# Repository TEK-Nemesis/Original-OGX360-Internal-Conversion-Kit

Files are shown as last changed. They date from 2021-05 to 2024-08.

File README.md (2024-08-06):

# Original OGX360 Internal Conversion Kit

This project allows an existing ogx360 to be nicely installed inside an original Xbox.

Note:  The ogx360 is a small circuit board which allows you to use a range of modern USB controllers on the Original Xbox Console.  It was designed by Ryzee119 (Ryan Wendland) and without him, I could not have made this product for the community.  https://github.com/Ryzee119/ogx360

Please consider donating to Ryan Wendland here:
<br>

## General:
* This project is a culmination of work that will aid with the installation of the original ogx360 (37mm x 97mm / 1.44 inches x 3.82 inches) inside an original Xbox.  
* Individual components of this project are organized into their own folder.
* If you don't already own an ogx360 then it is *not* recommended to use this kit.  If you are starting fresh then the better option is to use the newer internal OGX360i as it was made specifically to be installed inside an original Xbox.  (The TEK Nemesis OGX360i is very small in comparison to the original OGX360).

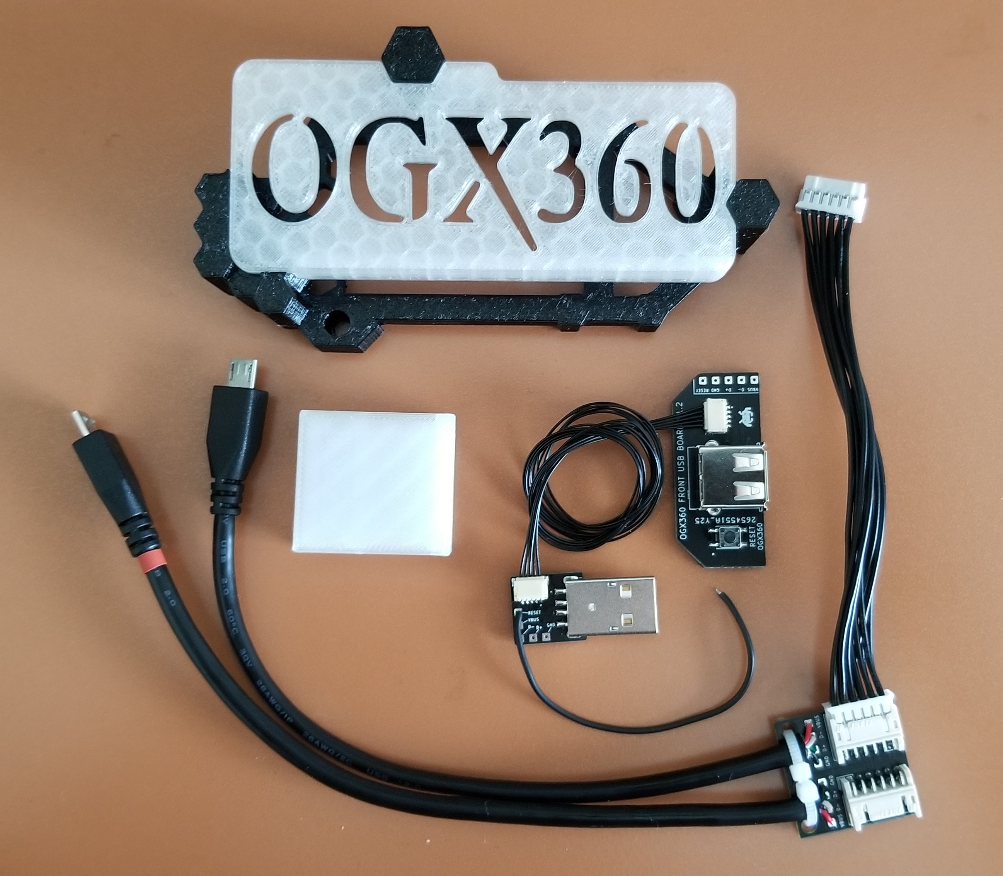
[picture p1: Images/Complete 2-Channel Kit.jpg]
 
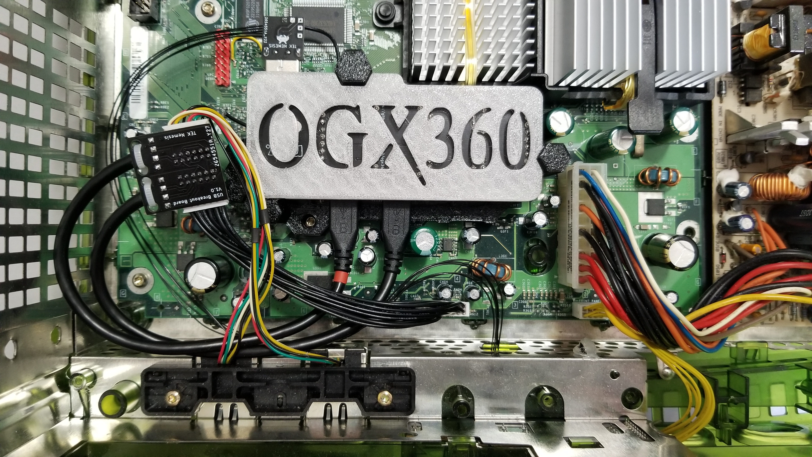
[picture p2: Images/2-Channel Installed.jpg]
 
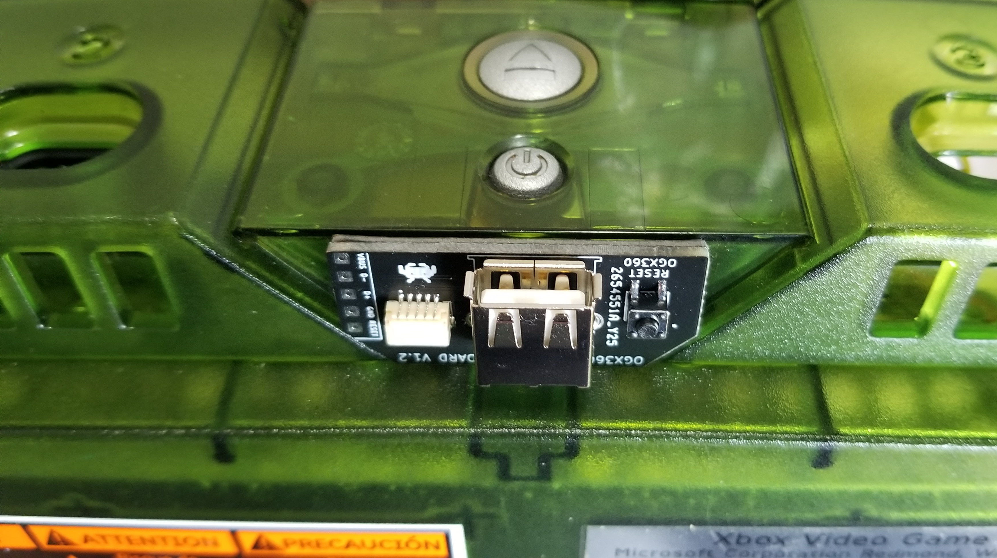
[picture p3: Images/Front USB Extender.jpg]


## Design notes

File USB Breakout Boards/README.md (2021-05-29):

# USB Breakout Boards

## Overview

* USB Breakout boards split USB functionality between the Xbox motherboard and the ogx360.  (The Xbox controller ports are actually proprietary USB ports.)

* I've included a little PCB that allows you two extend the 12-pin cable coming off the controller port.  Sometimes it is useful to use one with certain Xbox Revisions that don't have long Controller Port cables (e.g. 1.6).

* RYZEE119 designed the first USB Breakout Board to accept Micro USB to Micro USB Cables and 12-pin JST cables 2.00mm pitch.  The PCB is very small, measuring around 1 sq. in. in size.

* TEK Nemesis designed the second USB Breakout Board for direct wiring of the Micro USB cables to the PCB (and the same 12-pin JST cables 2.00mm pitch).

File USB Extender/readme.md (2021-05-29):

# USB Extender

## Overview

The USB Extender simply extends the USB port on the ogx360, bringing a USB port to the front of the Xbox.  

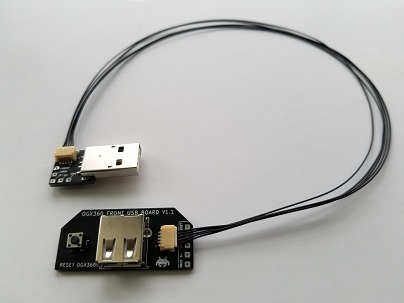
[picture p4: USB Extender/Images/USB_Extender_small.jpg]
 

## Usage

- The installation of a tactile switch on the Front USB PCB is optional but it may prove useful (perhaps when switching from wired to wireless controllers).  If used, here is what must be done:

   * If you **are** using a JST cable to connect the two USB Extender PCBs then you simply need to solder one end of a wire (e.g. 28 AWG multi-stranded) to the **reset** solder pad on the USB Plug PCB (that plugs directly into the ogx360).  The other end of the wire gets soldered to one of two inside pads of the tactile switch (that is soldered onto the ogx360).  Refer to the picture below.

   * If you **are not** using a JST cable to connect the two USB Extender PCBs then you will run one single wire (e.g. 28 AWG multi-stranded) from the **reset** solder pad on the Front USB PCB to one of two inside pads of the tactile switch (that is soldered onto the ogx360).  Refer to the picture below.
 
Note:  If everything is connected and the ogx360 doesn't reset then solder the reset wire to a different pad on the ogx360's tactile switch.  

- A 5-pin 1.00mm pitch JST cable is used to connect the two parts (although you may also wire directly to the solder pads.)

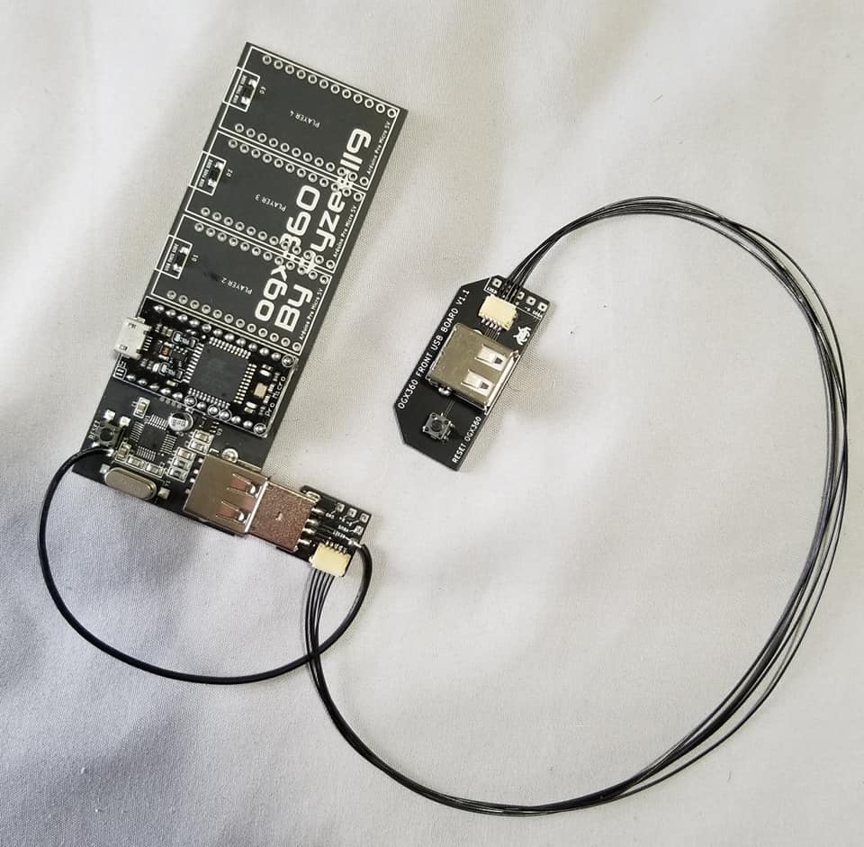
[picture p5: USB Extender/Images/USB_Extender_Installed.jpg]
 

## Gerber files

<b>USB 2.0 Plug for ogx360.zip</b> - plugs directly into the ogx360 USB Port.  A 5-pin cable runs out to the Front USB piece.  (Optionally, single wires may be used.)

<b>OGX360 Front USB PCB_Gerber Files (Type A).zip</b> - this PCB gets mounted outside the case, centred under the power/eject buttons.  Use double-sided tape to secure it.  5-pin connector points to <b>side</b>.   

<b>OGX360 Front USB PCB_Gerber Files (Type B).zip</b> - this PCB gets mounted outside the case, centred under the power/eject buttons.  Use double-sided tape to secure it.  5-pin connector points to <b>rear</b>.

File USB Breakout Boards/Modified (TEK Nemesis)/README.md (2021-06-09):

# USB Breakout Board (by TEK Nemesis)

## Overview

* This PCB was designed by TEK Nemesis. It uses Micro USB cables (cut open at one end) and 12-pin JST 2.00mm cables.  Zip ties / cable ties (optional) hold the wires nicely in place.
* This design allows for better cable management and routing.
* The Micro USB cable is soldered to the PCB like this (though it is possible to have alternate wire colours):
  - red wire to VBUS
  - black wire to GND
  - green wire to D+
  - white wire to D-
* Note that there are markings on the PCB to indicate the Controller Port:  P1/P3, P2/P4.  Plug the Micro USB cable into the appropriate Micro USB port on the ogx360.  I find it handy to add a little heatshrink band to the Micro USB cable that is for P1/P3.

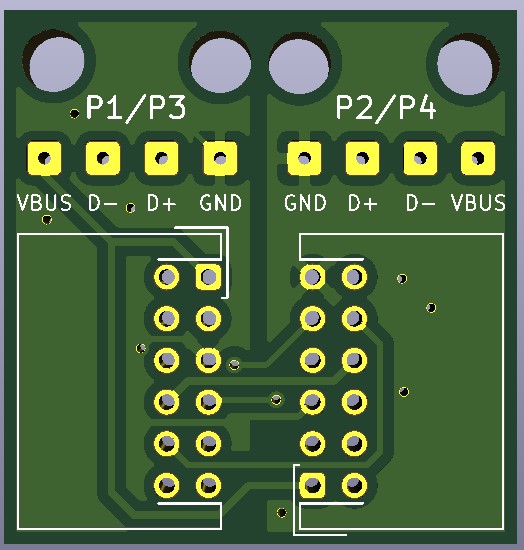
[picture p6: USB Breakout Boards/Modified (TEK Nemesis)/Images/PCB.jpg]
 

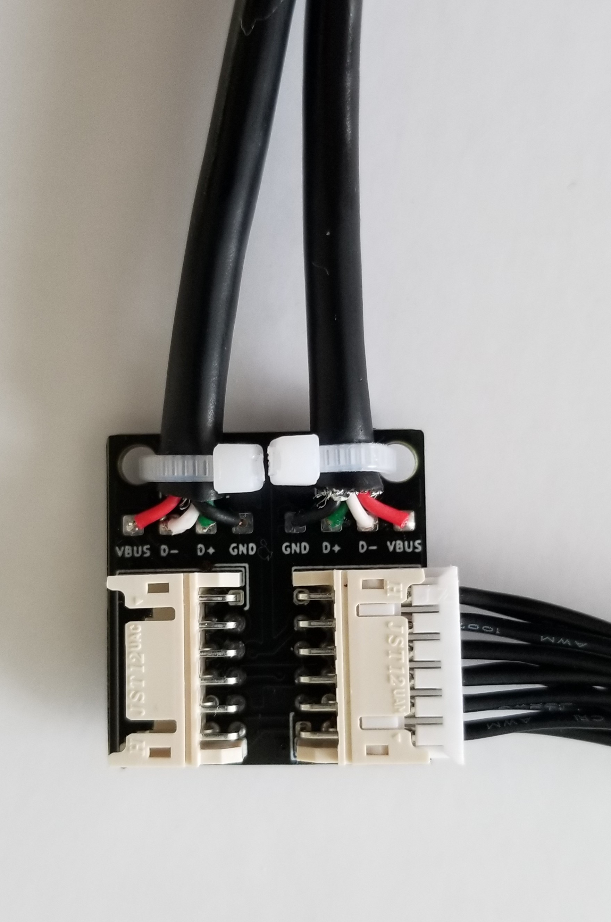
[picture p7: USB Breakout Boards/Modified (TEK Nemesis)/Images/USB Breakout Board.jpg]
 

## BOM

| Qty | Part Number | Manufacturer | Description | DigiKey Part |
|-----|---|---|---|---|
| 2 | S12B-PHDSS(LF)(SN) | JST Sales America Inc. | CONN HEADER R/A 12POS 2MM | 	455-1776-ND |
| 1 | CABLE | JST Sales America Inc. | PHD 2.0MM 26AWG CABLE, REVERSED | 	N/A |
| 1 | CABLE | N/A | Micro USB cable | 	N/A |

There is lots of stock of the 12-pin connection header on AliExpress:
https://www.aliexpress.com/wholesale?catId=0&initiative_id=SB_20210608224931&SearchText=S12B-PHDSS

AliExpress also has lots of the short PHD 2.0mm 26AWG cables (reversed, cable length should be around 10cm):
https://www.aliexpress.com/wholesale?catId=0&initiative_id=SB_20210608225500&SearchText=PHD+2.0mm+26awg

Any Micro USB cable will do as you'll be cutting off one end.  Nine to ten inches is a good length for this cable.

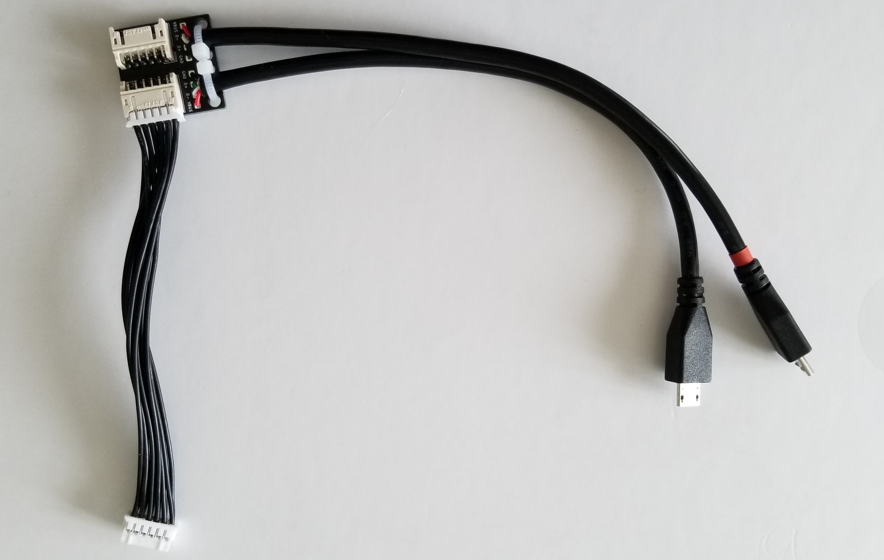
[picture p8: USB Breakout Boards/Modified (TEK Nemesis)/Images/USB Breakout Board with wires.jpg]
 

Here's the new USB Breakout board with the new 3D printed case:

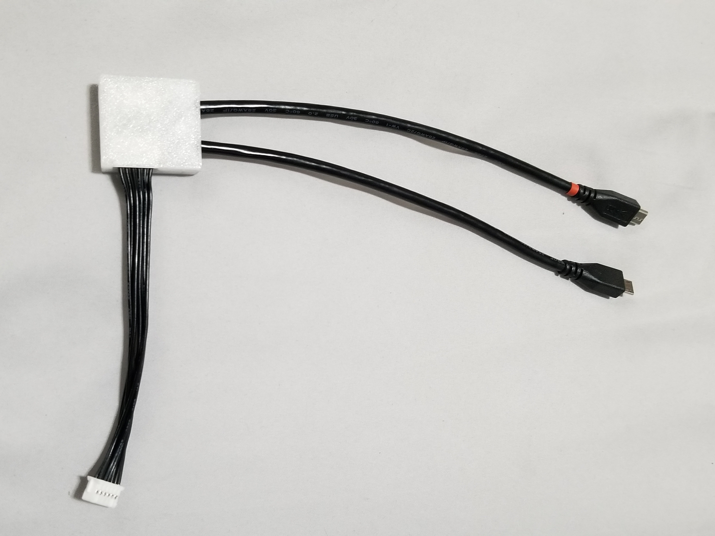
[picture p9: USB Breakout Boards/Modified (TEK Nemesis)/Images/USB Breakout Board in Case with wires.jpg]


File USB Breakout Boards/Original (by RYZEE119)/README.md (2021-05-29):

# USB Breakout Board (by RYZEE119)

## Overview

The PCB was designed by RYZEE119 and the STL was designed by TEK Nemesis.  The PCB uses Micro USB to Micro USB cables and 12-pin JST cables.

## BOM

| Qty | Part Number | Manufacturer | Description | DigiKey Part |
|-----|---|---|---|---|
| 2 | S12B-PHDSS(LF)(SN) | JST Sales America Inc. | CONN HEADER R/A 12POS 2MM | 	455-1776-ND |
| 2 | 10118193-0001LF | Amphenol ICC (FCI) | CONN RCPT USB2.0 MICRO B SMD R/A | 	609-4616-1-ND |

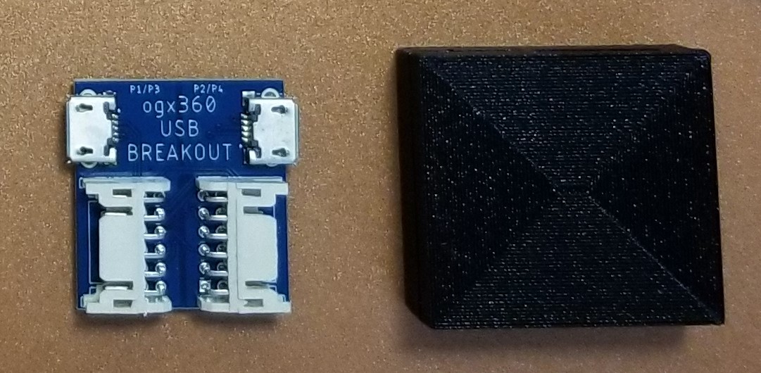
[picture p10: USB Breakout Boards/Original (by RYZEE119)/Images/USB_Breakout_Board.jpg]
 

Once installed, it will look like the image below.  (Note that there are markings on the PCB to indicate the Controller Port:  P1/P3, P2/P4.  Plug the Micro USB cable into the appropriate Micro USB port on the ogx360.)

The 3D printed part may be used or the USB Breakout Board may be affixed to the interior of the Xbox with double-sided tape.

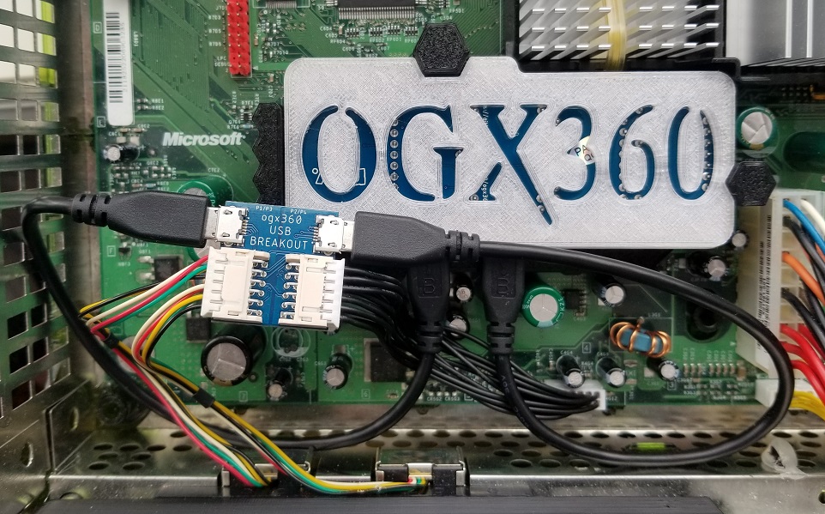
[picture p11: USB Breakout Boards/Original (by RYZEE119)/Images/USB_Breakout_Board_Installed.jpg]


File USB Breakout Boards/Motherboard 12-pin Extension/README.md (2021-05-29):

# Motherboard 12-pin Extension

## Overview

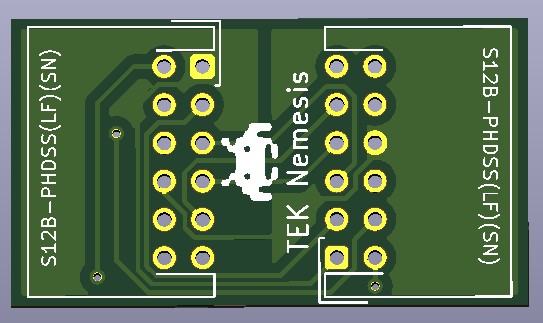
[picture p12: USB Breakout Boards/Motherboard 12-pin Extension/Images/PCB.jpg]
 

## BOM

| Qty | Part Number | Manufacturer | Description | DigiKey Part |
|-----|---|---|---|---|
| 2 | S12B-PHDSS(LF)(SN) | JST Sales America Inc. | CONN HEADER R/A 12POS 2MM | 	455-1776-ND |

This utility PCB plugs has many uses but it is mostly used for extending the controller port plug further away from the controller port. 

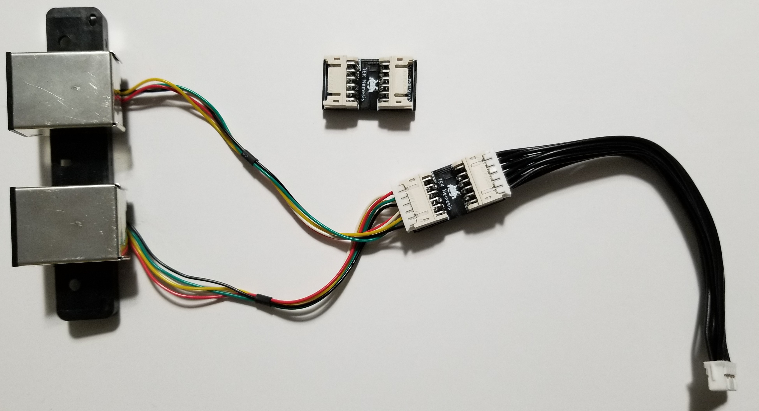
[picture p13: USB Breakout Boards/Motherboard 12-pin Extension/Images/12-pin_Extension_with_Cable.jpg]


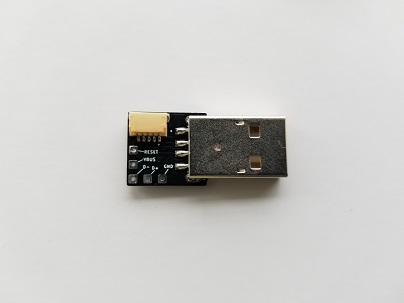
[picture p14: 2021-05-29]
USB Extender/Images/USB_Plug_small.jpg

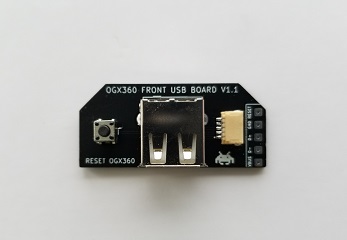
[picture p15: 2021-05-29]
USB Extender/Images/Front_USB_Port_small.jpg

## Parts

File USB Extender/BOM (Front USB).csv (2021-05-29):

Reference | Qty | Description | Part Number | Manufacturer | Digikey
J1 | 1 | CONN RCPT USB1.1 TYPEA 4POS R/A | AU-Y1005 | Assmann WSW Components | AE11181-ND
J2 | 1 | CONN HEADER SMD R/A 5POS 1MM | SM05B-SRSS-TB(LF)(SN) | JST Sales America Inc. | 455-1805-1-ND
S1 | 1 | TL3305AF160QG | TL3315NF160Q | E-Switch | EG5350CT-ND

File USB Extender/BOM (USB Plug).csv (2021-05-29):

Reference | Qty | Description | Part Number | Manufacturer | Digikey
J1 | 1 | CONN PLUG USB2.0 TYPEA 4P SMD RA | 1-1734028-1 | TE Connectivity AMP Connectors | A122942CT-ND
J2 | 1 | CONN HEADER SMD R/A 5POS 1MM | SM05B-SRSS-TB(LF)(SN) | JST Sales America Inc. | 455-1805-1-ND

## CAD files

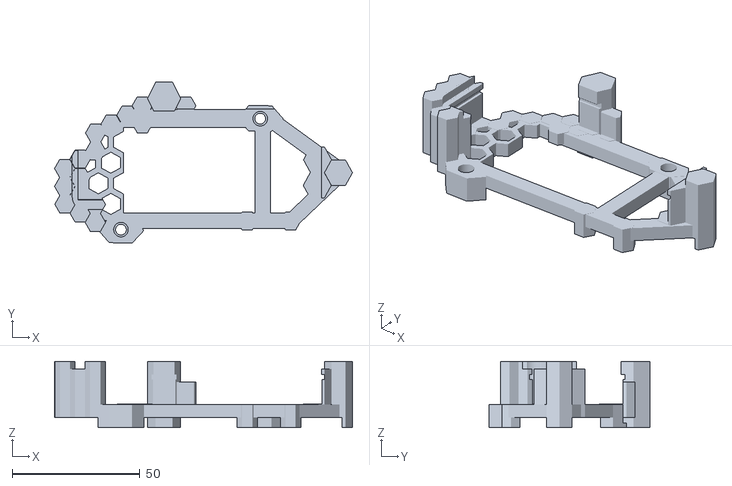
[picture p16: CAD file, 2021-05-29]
3D Printed Caddy/STL/OGX360 Caddy Bottom v.1.4.stl
116.7 x 63.1 x 25.9

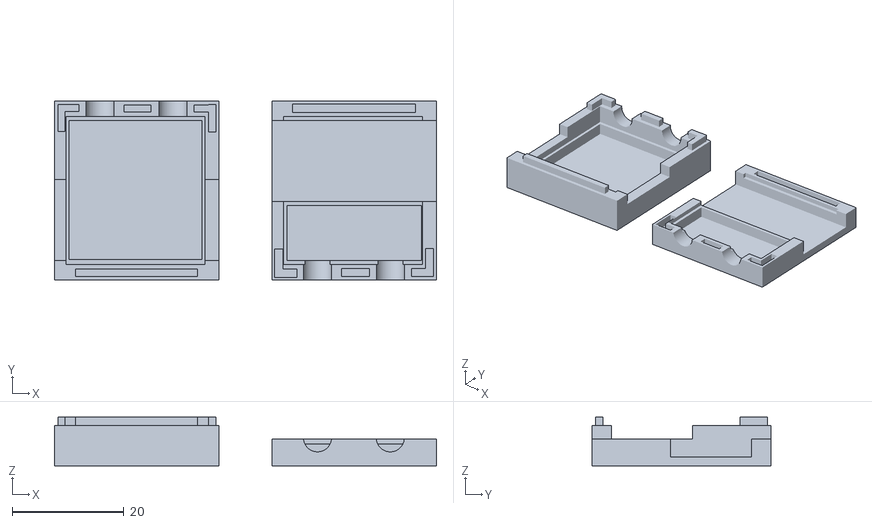
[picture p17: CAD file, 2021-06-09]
USB Breakout Boards/Modified (TEK Nemesis)/STL/OGX360 USB Breakout Board v.1.5.stl
68.2 x 32.0 x 8.70

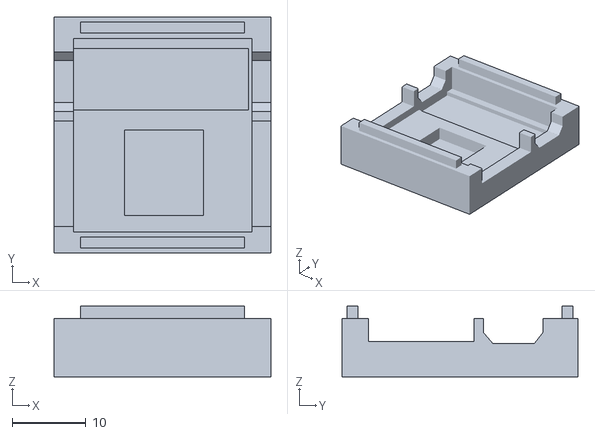
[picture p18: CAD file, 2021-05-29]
USB Breakout Boards/Original (by RYZEE119)/STL/OGX360 USB Breakout Board v.1.4 (part 1).stl
29.4 x 32.0 x 9.61

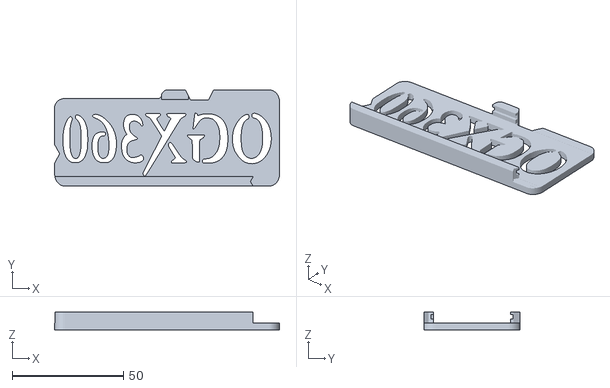
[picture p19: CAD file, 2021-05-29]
3D Printed Caddy/STL/OGX360 Caddy Top v.1.4.stl
101.1 x 43.2 x 8.00

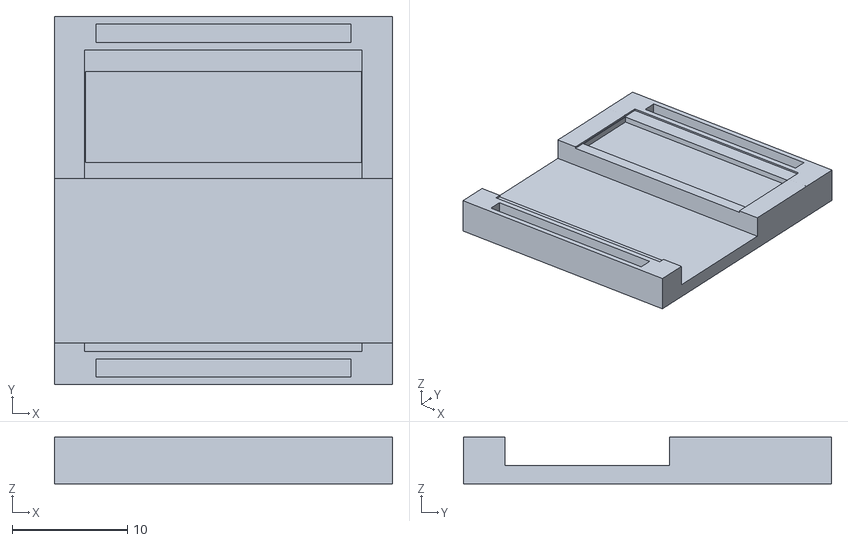
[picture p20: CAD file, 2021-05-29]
USB Breakout Boards/Original (by RYZEE119)/STL/OGX360 USB Breakout Board v.1.4 (part 2).stl
29.4 x 32.0 x 4.06

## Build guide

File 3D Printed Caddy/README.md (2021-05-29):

# 3D Printed Caddy

## Overview

The caddy was designed by TEK Nemesis and it is used to hold the ogx360 in place (inside the Xbox, with the original motherboard screws).  The caddy isn't necessary but it has a unique look and it properly secures the ogx360 from moving around.

Note:  The Philips DVD Drive has a big bulge on the bottom that interferes with this caddy.  The Philips drive can be swapped with any other DVD drive that comes with the Xbox.

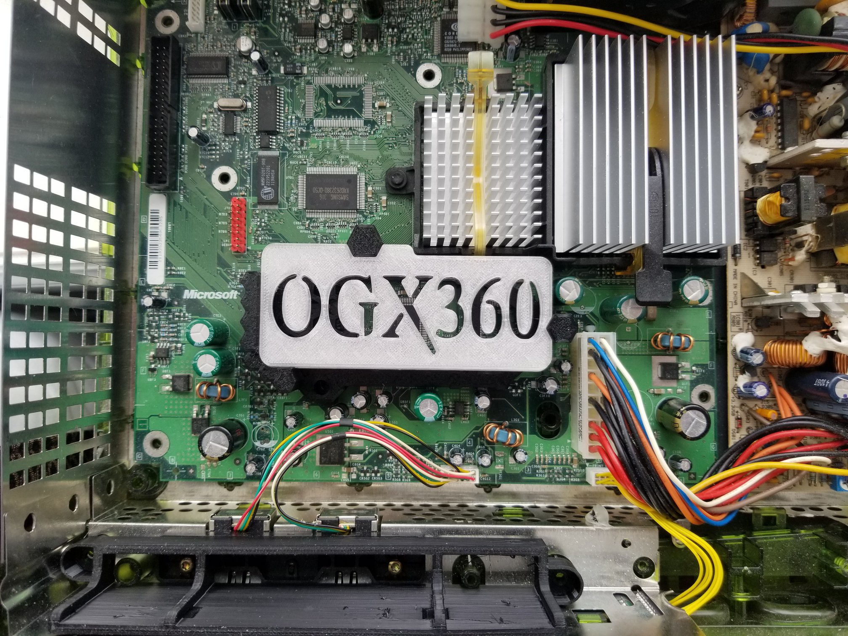
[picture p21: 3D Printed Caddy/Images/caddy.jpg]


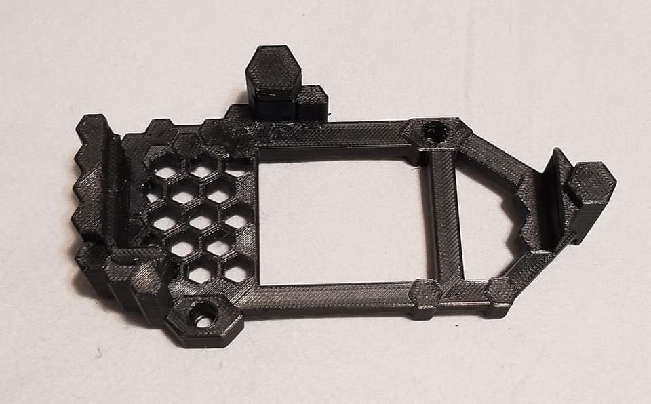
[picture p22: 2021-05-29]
3D Printed Caddy/Images/caddy_bottom.jpg

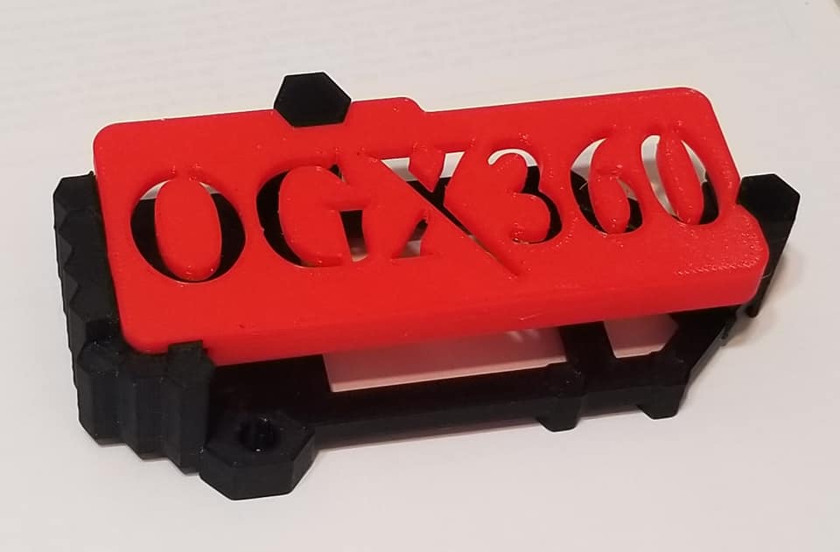
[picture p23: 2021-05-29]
3D Printed Caddy/Images/caddy_red_black.jpg

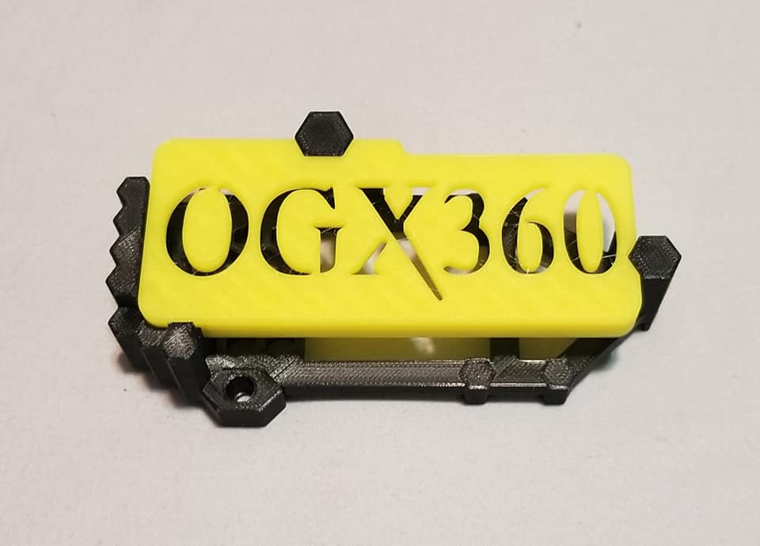
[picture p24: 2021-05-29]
3D Printed Caddy/Images/caddy_yellow_blk.jpg
